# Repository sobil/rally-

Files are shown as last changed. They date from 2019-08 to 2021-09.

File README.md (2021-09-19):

# Rally-
_Pronounced "Rally Dash"_

This code is designed to be used as a trip computer, speedo, odometer.

Presently it simply implements twin independent odometers using the internal clock on the atmel chip.

The code was designed for use on a micro arduino using a SPI driven 240X128 LCD graphical display and a hall sensor. Unlike many other examples this code uses the internal counter on the CPU and should be more reliable than other interrupt and pin check loop methods.

PRs and issues welcome. I plan to include more hardware details in time.

## Parts List

Noteable:
- *LCD:* https://www.buydisplay.com/serial-graphic-module-display-240x128-cog-with-uc1608-controller
- *HALL sensor:* A3144 Sensor https://components101.com/sensors/a3144-hall-effect-sensor
- *CONNECTORS:* JST PH2.0  (2Pin 3Pin 4Pin 5Pin)
- *BUTTONS:* https://www.jaycar.com.au/ip67-rated-dome-pushbutton-switch-black/p/SP0656

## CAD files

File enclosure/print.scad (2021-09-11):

// RALLY- Enclosure
edge_radius = 4;
depth = 12; d = depth;
width = 135; w = width;
height = s[1]+4*screw_size++2*wall_thickness; h = height;
wall_thickness = 2;
button_hole_diameter=12;
circle_resolution=10;
screen_offset_distance=width-s[0]-2*wall_thickness-2*edge_radius-8;
screw_size=3;
so = [71,39]; screen_opening = so;
s = [86.5,54.5,wall_thickness]; screen = s;
b= [97,54,2]; board=b;
back_depth=25;
mount_bolt_spacing=80;

//spacer
//translate([0,0,50]) screen_spacer(2,97,54,6,3);

//Retainer
//translate([0,100,100]) mirror([0,1,0]) board_retainer(screw_size);

//Face
//face();

//Back plate
//translate([0,100,200]) back();

module back() {
  union() {
      difference() {
          box(back_depth-wall_thickness, w, h, edge_radius, wall_thickness,top=0); 
          translate([w/2-mount_bolt_spacing/2,h/2,0]) hull() bolt_boss(head=10,shank=6,wall=wall_thickness);
          translate([w/2+mount_bolt_spacing/2,h/2,0]) hull() bolt_boss(head=10,shank=6,wall=wall_thickness);
      }
      //inner rim (gotta be a better way)
      difference() {
          box(back_depth, w, h, edge_radius, wall_thickness,top=0);
          box(back_depth, w, h, edge_radius, wall_thickness,top=1);
      }
      translate([w/2-mount_bolt_spacing/2,h/2,0]) bolt_boss(head=10,shank=6,wall=wall_thickness);
      translate([w/2+mount_bolt_spacing/2,h/2,0]) bolt_boss(head=10,shank=6,wall=wall_thickness);
   } 
}

module bolt_boss(head, shank, wall) {
    difference() {
      color("red") cylinder(h=3*wall_thickness,d2=head+wall_thickness*2, d1=head+wall_thickness*6, $fn=circle_resolution);
      color("red") translate([0,0,wall*1.5]) cylinder(h=4*wall_thickness,d=head, $fn=6);
      color("red") cylinder(h=4*wall_thickness,d=shank, $fn=circle_resolution);
    }
}

module face() {
    //button holes
    button_spread=0.65;
    difference() {
        box(d, w, h, edge_radius, wall_thickness,top=1);
        hull() translate([screen_offset_distance,s[1]+wall_thickness+4*screw_size,0]) mirror([0,1,0]) screen_mount(wall_thickness,s);
        color ("blue") translate([1.5*button_hole_diameter,(1-button_spread)*h*.5,0]) rotate([0,0, 0]) holes(button_hole_diameter, 3, h*button_spread, wall_thickness);
    }   
    translate([screen_offset_distance,s[1]+wall_thickness+4*screw_size,0]) mirror([0,1,0]) screen_mount(wall_thickness,s);
}

module box(d, w, h, r, wall, top=0) {
    o = 0; origin = o;
    difference() {
        //the outer box
        outer(w,h,d,r);
        //make hollow
        translate([wall, wall, wall]) scale([((w - 2 * wall) / w),((h - 2 * wall) / h),1]) outer(w,h,d,r);
        //add outside step
        if (top==1) translate([wall/2, wall/2, d-wall]) scale([((w - wall) / w),((h - wall) / h),1]) outer(w,h,d,r);
        if (top==1) screw_holes(post_diameter=r*2, screw_diameter=2.8,length=d-wall,x=w-wall,y=h-wall);
        // remove the screw post before adding it back in (so the screw holes dont get blocked up
        if (top==0) translate([wall/2,wall/2,0]) screw_holes(post_diameter=r*2, screw_diameter=0,length=d,x=w-wall,y=h-wall);
            
    }
    //screw holes
    if (top==1) translate([wall/2,wall/2,0]) screw_holes(post_diameter=r*2, screw_diameter=2.8,length=d-wall,x=w-wall,y=h-wall);
    if (top==0) {
        translate([wall/2,wall/2,0]) screw_holes(post_diameter=r*2, screw_diameter=screw_size*2,length=d-wall,x=w-wall,y=h-wall);
        translate([wall/2,wall/2,d-wall]) screw_holes(post_diameter=r*2, screw_diameter=screw_size,length=wall,x=w-wall,y=h-wall);
        
    }

    module outer(x,y,z,r) {
       hull() screw_holes(post_diameter=r*2,length=z,x=x,y=y);
    }

    module screw_holes(post_diameter, screw_diameter, length,x,y) {
        od = post_diameter;
        r = post_diameter/2;
        translate([r, r, o]) tube(od, screw_diameter, length);
        translate([x - r, y - r, o]) tube(od, screw_diameter, length);
        translate([x - r, o + r, o]) tube(od, screw_diameter, length);
        translate([o + r, y - r, o]) tube(od, screw_diameter, length);
    }
};

module holes(diameter, number = 1, spread = 0, depth=wall_thickness) {
    if (spread > 0) {
        spacing = spread / (number-1);
        translate([o, o, o]) for (i = [0: number-1]) {
            translate([0, i * spacing, 0]) cylinder(depth, d = diameter, $fn=circle_resolution);
        }
    }
    else {
        spacing = (diameter * 1.5);
        translate([diameter/2, diameter/2, o]) for (i = [0: number - 1]) {
            translate([0, i * spacing, 0]) cylinder(depth, d = diameter, $fn=circle_resolution);
        }
    }
}

module screen_mount(wall,screen) {
  so_vertical_offset = 12;
  lr = [s[0]+wall*2,s[1]+(wall*2),2*wall];locating_ring =lr;
  screen_thickness=5;
  clearance=3;

  difference() {
    union() {
        cube([s[0]+2*wall,s[1]+4*screw_size,wall]);
        difference(){
            translate([0,2*screw_size-wall,0]) cube(lr);
            //space for the little bump on the screen
            translate([wall/2,2*screw_size+so[1]/2-5+so_vertical_offset,0]) cube([lr[0]-wall,10,lr[2]]);
        }
    }
    color("red") translate([(lr[0]-so[0])*.5,2*screw_size-wall+so_vertical_offset+wall,0]) cube([71,39,wall*20]);
    color("blue") translate([(lr[0]-s[0])/2,2*screw_size-wall+(lr[1]-s[1])/2,wall]) cube([s[0],s[1],wall*2]);
    color("green") translate([(lr[0]-s[0])/2,2*screw_size-wall+(lr[1]-s[1])/2,wall]) cube([s[0],s[1],wall*2]);
  }
    screen_screw_blocks(screw_size-.1,wall+screen_thickness+clearance,screen,wall);
    height = wall+screen_thickness+clearance;

};

  module screen_screw_blocks(screw_size,height,screen,wall,block_size=screw_size*2) {
    screw_block(block_size,height,screw_size);
    translate([0,screen[1]+block_size,0]) screw_block(block_size,height,screw_size);
    translate([screen[0]+2*wall-block_size,screen[1]+block_size,0]) screw_block(block_size,height,screw_size);  
    translate([screen[0]+2*wall-block_size,0,0]) screw_block(block_size,height,screw_size);
  }
  
  module screw_block(block_width,depth,hole_size=0) {
    b=block_width;
    difference() {
        cube([b,b,depth]);
        translate([b/2,b/2,]) cylinder(depth,d=hole_size, $fn=circle_resolution);
    }
  }

module tube(od=10, id=5, h) {
    difference() {
        cylinder(h, r = od / 2, $fn = circle_resolution);

        cylinder(h, r = id / 2, $fn = circle_resolution);
    }
}

module board_retainer(screw_size) {
  screw_lug_offset=3;
  difference() {  
    union() {
      translate([0,2*screw_size-wall_thickness,0]) difference() {
        //outer rim  
        cube([b[0]+2*wall_thickness,b[1]+2*wall_thickness,3*wall_thickness]);
        translate([wall_thickness,wall_thickness,0]) cube([b[0],b[1],wall_thickness*2]);
        translate([wall_thickness*2,wall_thickness*2,0]) cube([b[0]-2*wall_thickness,b[1]-2*wall_thickness,wall_thickness*3]);
      }
      translate([23.5+wall_thickness,screw_size*2-wall_thickness,wall_thickness*2]) cube([45,15,wall_thickness]);
    }
    //create void for screw lugs
    translate([screw_lug_offset,0,0]) screen_screw_blocks(0,wall_thickness*3,s,wall_thickness,screw_size*2);
    //gap for ribbon cable
    translate([33.5+wall_thickness,screw_size*2-wall_thickness,0]) cube([25,8,wall_thickness*4]);
  translate([23.5+wall_thickness,screw_size*2-wall_thickness,0]) cube([45,15,wall_thickness*2]);
  }
  //create screw lugs
  translate([screw_lug_offset,0,0]) screen_screw_blocks(screw_size+.2,wall_thickness*3,s,wall_thickness,screw_size*2);
}

module screen_spacer(height,width,depth, standoff_width, standoff_height) {
    translate([0,0,height]) cube([standoff_width,standoff_width,standoff_height]);
    translate([width-standoff_width,0,height]) cube([standoff_width,standoff_width,standoff_height]);
    translate([width-standoff_width,depth-standoff_width,height]) cube([standoff_width,standoff_width,standoff_height]);
    translate([0,depth-standoff_width,height]) cube([standoff_width,standoff_width,standoff_height]);
    hole_percentage=0.7;
    difference (){
        translate([0,0,0]) cube([width,depth,height]);
        translate([width/2-width*hole_percentage/2,depth/2-depth*hole_percentage/2,0]) cube([width*hole_percentage,depth*hole_percentage,height]);

   }
}

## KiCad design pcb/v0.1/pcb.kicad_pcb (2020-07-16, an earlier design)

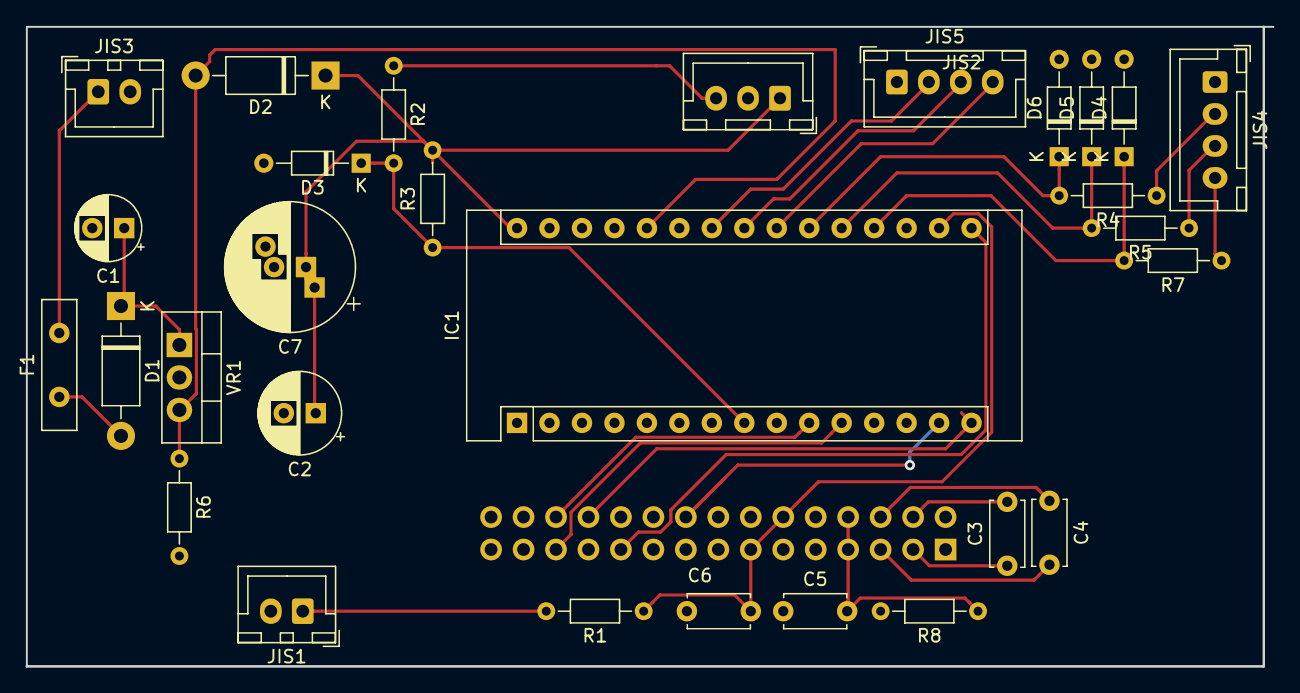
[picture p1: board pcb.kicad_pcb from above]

Board: 2 copper layers, 97.5 x 50.0 mm, 30 parts (1 on the bottom side), 29 nets.

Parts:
C1: 200uF; CP_Radial_D5.0mm_P2.50mm
C2: 100uF; CP_Radial_D6.3mm_P2.50mm
C3, C4: 4.7uF; C_Disc_D5.0mm_W2.5mm_P5.00mm
C5, C6: 0.1uF; C_Disc_D4.7mm_W2.5mm_P5.00mm
C7: 5.5V 0.47F; CP_Radial_D10.0mm_P2.50mm_P5.00mm
D1: 1N4007; D_DO-41_SOD81_P10.16mm_Horizontal
D2: 1N4001; D_DO-41_SOD81_P10.16mm_Horizontal
D3, D4, D5, D6: D_Zener_Small; D_DO-34_SOD68_P7.62mm_Horizontal
Display1: LCD; PinHeader_2x15_P2.54mm_Vertical
F1: Polyfuse 500ma 60V; C_Disc_D10.0mm_W2.5mm_P5.00mm
IC1: Nano_v3.x; Arduino_Nano
JIS1: LCD_BL; JST_XH_B02B-XH-A_1x02_P2.50mm_Vertical
JIS2: Speedo Connector; JST_XH_B03B-XH-A_1x03_P2.50mm_Vertical
JIS3: Power Connector; JST_XH_B02B-XH-A_1x02_P2.50mm_Vertical
JIS4: external button connector; JST_XH_B04B-XH-A_1x04_P2.50mm_Vertical
JIS5: int key; JST_XH_B04B-XH-A_1x04_P2.50mm_Vertical
R1: R4.3; R_Axial_DIN0204_L3.6mm_D1.6mm_P7.62mm_Horizontal
R2, R4, R5, R7: R100; R_Axial_DIN0204_L3.6mm_D1.6mm_P7.62mm_Horizontal
R3, R6: R10K; R_Axial_DIN0204_L3.6mm_D1.6mm_P7.62mm_Horizontal
R8: 10M; R_Axial_DIN0204_L3.6mm_D1.6mm_P7.62mm_Horizontal
VR1: LM7805_TO220; TO-220-3_Vertical

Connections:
+3V3: C6.2, Display1.12, Display1.13, IC1.17, R1.1
+5V: C2.1, C7.1, D2.1, IC1.30, JIS2.1, R3.2
+BATT: F1.2, JIS3.1
GND: C1.2, C2.2, C5.1, C6.1, C7.2, D3.2, D4.2, D5.2, D6.2, Display1.2, Display1.10, Display1.11, Display1.16, Display1.19, Display1.20, Display1.23, Display1.27, Display1.28, Display1.29, IC1.4, IC1.29, JIS1.2, JIS2.2, JIS3.2, JIS4.1, JIS5.1, R6.2, R8.2, VR1.2
unnamed: C1.1, D1.1, VR1.1
unnamed: C3.1, Display1.3
unnamed: C3.2, Display1.4
unnamed: C4.1, Display1.6
unnamed: C4.2, Display1.5
unnamed: C5.2, Display1.7, Display1.8, R8.1
unnamed: D1.2, F1.1
unnamed: D2.2, IC1.26, R6.1, VR1.3
unnamed: D3.1, IC1.8, R2.2, R3.1
unnamed: D4.1, IC1.19, R7.2
unnamed: D5.1, IC1.20, R5.2
unnamed: D6.1, IC1.21, R4.2
unnamed: Display1.18, IC1.14
unnamed: Display1.21, IC1.16
unnamed: Display1.24, IC1.15
unnamed: Display1.25, IC1.11
unnamed: Display1.26, IC1.10
unnamed: IC1.22, JIS5.4
unnamed: IC1.23, JIS5.3
unnamed: IC1.24, JIS5.2
unnamed: JIS1.1, R1.2
unnamed: JIS2.3, R2.1
unnamed: JIS4.2, R4.1
unnamed: JIS4.3, R5.1
unnamed: JIS4.4, R7.1

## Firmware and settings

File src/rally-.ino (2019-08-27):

//#include "Wire.h"
#include <Arduino.h>
#include <EEPROM.h>
#include <U8g2lib.h>

#ifdef U8X8_HAVE_HW_SPI
#include <SPI.h>
#endif

#define cbi(sfr, bit) (_SFR_BYTE(sfr) &= ~_BV(bit))
#define sbi(sfr, bit) (_SFR_BYTE(sfr) |= _BV(bit))

U8G2_UC1608_240X128_1_4W_SW_SPI
u8g2(U8G2_R0,
     /* clock=*/13,
     /* data=*/11,
     /* cs=*/7,
     /* dc=*/12,
     /* reset=*/8); // SW SPI, Due ERC24064-1 Test Setup

int count;
int cal;
int cum_places = 2;
int int_places = 2;
double cum_rotations = 0;
double int_rotations = 0;
int option = 0;
float cumulative = 0;
float intermediate = 0;
char MENU_ITEMS[5][6] = {{'n', 'u', 'l', 'l'},
                         {'n', 'u', 'l', 'l'},
                         {'n', 'u', 'l', 'l'},
                         {'c', 'a', 'l', 'i'},
                         {'e', 'x', 'i', 't'}};
int hold;
char lastkey;

void get_stored_cal()
{
  EEPROM.get(0, cal);
}

void set_stored_cal(int val)
{
  EEPROM.put(0, val);
}

void reset_counter()
{
  // configure Counter 1
  cbi(TCCR1A, WGM11);
  cbi(TCCR1A, WGM10);
  cbi(TCCR1B, WGM12); // WGM12::WGM10 000 - Normal mode
  sbi(TCCR1B, CS12);  // CS12::CS10 111 - External clock, count on rising edge.
  sbi(TCCR1B, CS11);
  sbi(TCCR1B, CS10);
  TCNT1 = 0x0000; // note that TCNT1 is 16-bits
                  // not sure if should turn off the counter
}

char get_button_pressed()
{
  if ((digitalRead(A1) == LOW)) {
    return 0xB0; // KEY_RETURN;
  } else if ((digitalRead(A0) == LOW)) {
    return 0xD9; // KEY_DOWN_ARROW;
  } else if ((digitalRead(A2) == LOW)) {
    return 0xDA; // KEY_UP_ARROW;
  } else {
    return 0;
  }
}

void drawBorders(void)
{
  u8g2.drawFrame(1, 1, 180, 64);   // boxA
  u8g2.drawFrame(1, 64, 180, 64);  // boxB
  u8g2.drawFrame(180, 1, 60, 127); // boxC
}

void boxA(float val,int digits)
{
  u8g2.setFont(u8g2_font_logisoso54_tn);
  u8g2.setCursor(2,60);
  u8g2.print(val,digits);
}

void boxB(float val,int digits) {
  u8g2.setFont(u8g2_font_logisoso54_tn);
  u8g2.setCursor(2,124);
  u8g2.print(val,digits);
}

void boxC(char text[5][6], int option)
{
  for (int i = 0; i < 5; i++) {
    if (i == option) {
      u8g2.setFont(u8g2_font_fub17_tr);
    } else {
      u8g2.setFont(u8g2_font_fur17_tr);
    }
    u8g2.drawStr(182, (i+1) * 20, text[i]);
  }
}

void setup(void)
{
  // Serial.begin(9600);
  u8g2.begin();
  u8g2.setContrast(10);
  get_stored_cal();
  // Serial.print("Calibration: ");
  // Serial.println(cal);
  pinMode(5, INPUT_PULLUP);
  pinMode(A0, INPUT_PULLUP);
  pinMode(A1, INPUT_PULLUP);
  pinMode(A2, INPUT_PULLUP);
  cum_rotations = 0;
  int_rotations = 0;
}

void update_dist()
{
  int diff = TCNT1;
  reset_counter();
  cum_rotations += TCNT1;
  int_rotations += TCNT1;
  cumulative = (cum_rotations * cal) / 1000000;
  intermediate = (int_rotations * cal) / 1000000;
  cum_places = (cumulative >= 100) ? 1 : 2;
  int_places = (intermediate >= 100) ? 1 : 2;
  if (cumulative >= 999)
    cumulative = 0;
  if (intermediate >= 999)
    intermediate = 0;
};

void menu()
{
  option = 4;
  // Serial.println("In Menu");
  while (option < 6) {
    u8g2.firstPage();
    do {
      drawBorders();
      boxA(cumulative,cum_places);
      //boxB(intermediate,int_places);
      boxC(MENU_ITEMS, option);
    } while (u8g2.nextPage());
    // delay(100);
    char pressed = get_button_pressed();
    switch (pressed) {
    case char(0xD9): {
      option = (option < 6) ? (option + 1) : option;
      // option++;
    } break;
    case char(0xDA): {
      option = (option > 0 ) ? (option - 1) : option;
    } break;
    case char(0xB0): // on enter
    {
      if (lastkey != pressed) {
      switch (option) {
      case 3:
        calibration();
        break;
      case 4:
        option = 9;
        break;
      default:
        break;
      }
      }
    }
    default:
      // nothing
      break;
    }
    lastkey = pressed;
  }
}

void calibration()
{
  char thiskey = 'o';
  delay(200);
  int increment = 1;
  while (thiskey != char(0xB0)) { 
  u8g2.firstPage();
  do {
    drawBorders();
    boxA(cal,0);
    //boxB(cumulative);
    //boxC(MENU_ITEMS, option);
  } while (u8g2.nextPage());
  thiskey = get_button_pressed();
  if (thiskey == char(0xDA)) // up
  {
    increment = 1;
  } else if (thiskey == char(0xD9)) // down
  {
    increment = -1;
  } else {
    hold = 0;
    increment = 0;
  }
  if (lastkey == thiskey) {
    hold++;
    if (hold > 5) {
      increment = increment + increment;
    }
  }
  else {
    hold = 0;
  }
  lastkey = thiskey;
  cal = cal + increment;
  delay(300);
  }
  set_stored_cal(cal);
}

void loop(void)
{
  char thiskey = get_button_pressed();
  if ((lastkey == thiskey) && (thiskey == char(176))) { // KEY_RETURN
    hold++;
    if (hold = 10) {
      menu();
    }
  } 
  else if (thiskey == char(0xDA)) // up
  {
    cum_rotations = 0;
  } else if (thiskey == char(0xD9)) // down
  {
    int_rotations = 0;
  } else {
    hold = 0;
  }
  lastkey = thiskey;
  update_dist();
  u8g2.firstPage();
  do {
    drawBorders();
    boxA(cumulative,cum_places);
    boxB(intermediate,int_places);
  } while (u8g2.nextPage());
  cum_rotations++;
  int_rotations++;
}

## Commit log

2020-07-16 update PCB
    [pcb-v2.kicad_pcb, pcb.kicad_pcb, pcb.sch]
2021-09-05 scadfile between circuit board and screen
    [print.scad]
2021-09-05 removing comments
    [print.scad]
2021-09-07 update: Enclosure WIP
    [print.scad]
2021-09-11 add enclosure back
    [print.scad]
